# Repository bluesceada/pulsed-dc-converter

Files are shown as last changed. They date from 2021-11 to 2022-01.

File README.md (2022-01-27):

# pulsed-dc-converter
12-20V DC to Pulsed DC Converter

Transforms 12-20V DC to a kind of pulsed DC, compatible with some Power Tools using phase cutting
control (for example Proxxon Micromot), in the range up to around 40W.

Like that, with the respective Adapter, those small Power Tools can be operated from a USB C PD
Power Bank. Adapter Example: https://aliexpress.com/wholesale?SearchText=power+adapter+usb+c+dc+20v

**Progress:**

 [x] Simple loop works on breadboard with similar schematic as in kicad
 
 [x] PCB designed and ordered
 
 [x] PCB tested and working with 12V/1.5A from USB-C Powerbank and 20V/3A from USB-C Power Supply (with respective USB-C Adapters). Populated parts are mainly as in the schematic, except the Zener(D3) in the flyback path is just bridged with a wire, see [21861574f8b53dd02fe86965473d7c7fb414512f](https://github.com/bluesceada/pulsed-dc-converter/commit/21861574f8b53dd02fe86965473d7c7fb414512f)
 
 [x] Use ADC feedback to increase the ON-time of the transistor to maximize power for powerbanks

**Note:** I still have PCBs ([Rev-0.1](https://github.com/bluesceada/pulsed-dc-converter/releases/tag/Rev-0.1)) available, message me if you are interested to get it for net cost, ~1€ + shipping from DE/Germany 🇩🇪. I also still have 2x attiny85 that I could pre-program if needed. The only real PCB-errata is a missing connection of Attiny Pin 5 (PB0) to R1, which is easily bridged.

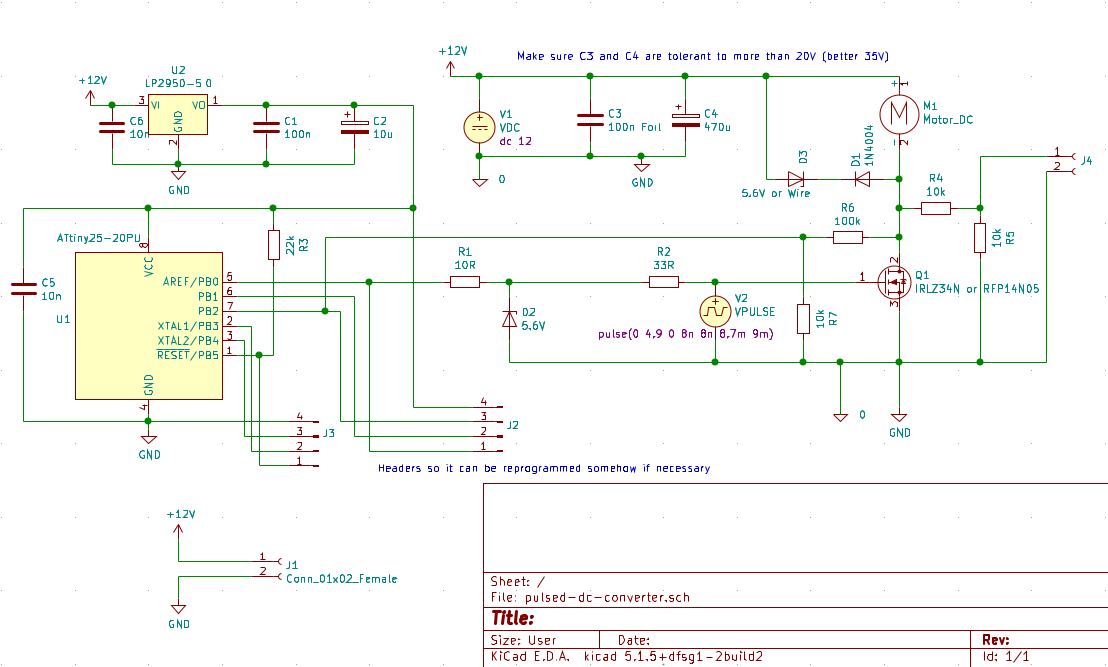
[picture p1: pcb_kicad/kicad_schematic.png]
kicad schematic


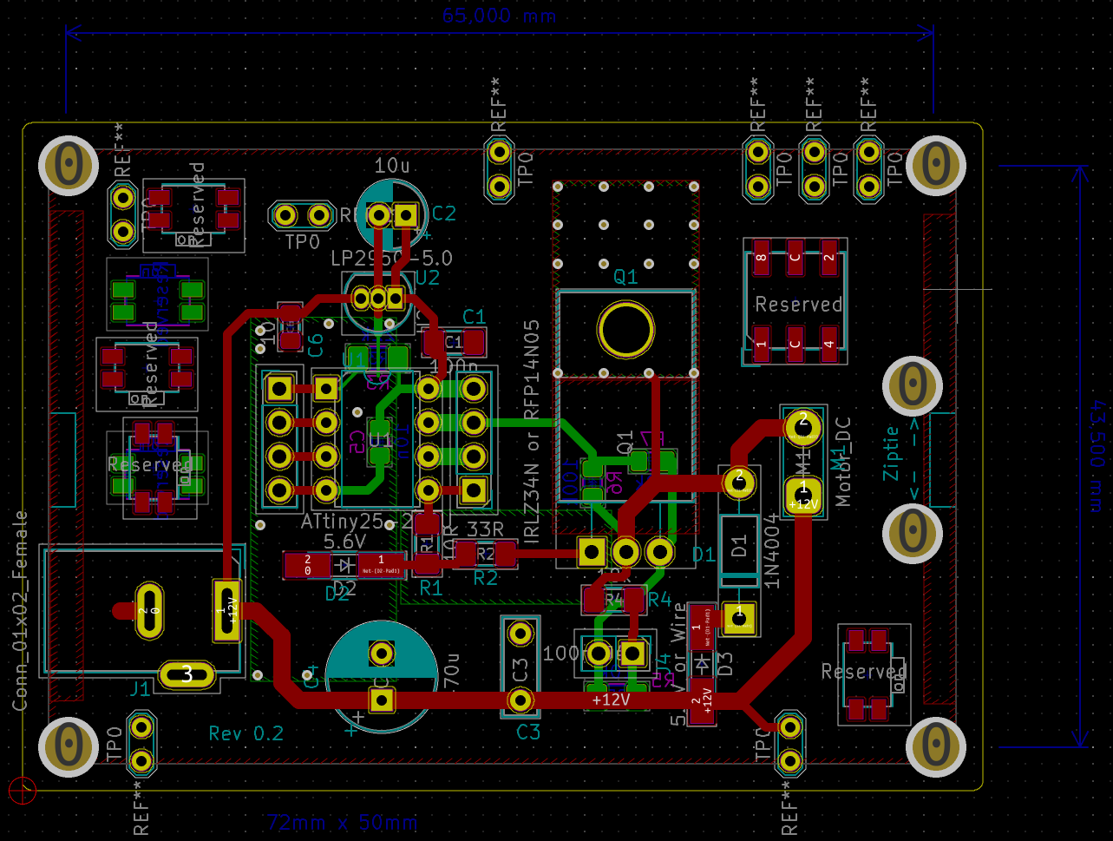
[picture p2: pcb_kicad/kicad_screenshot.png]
kicad pcb


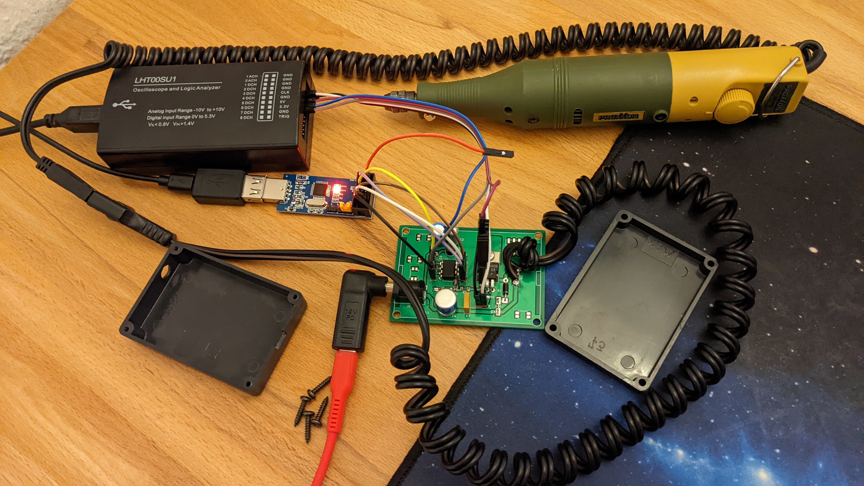
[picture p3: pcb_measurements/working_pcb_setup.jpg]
real hardware pcb setup picture


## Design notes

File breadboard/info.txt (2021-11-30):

You can open the *.pr files with sigrok's "pulseview".

Measurements were on a 19V/12V Supply Voltage from a 65W USB-C Power Supply. Transistors IRLZ34N or RFP14NO5 were used (leading to very similar results). The analog measurements were done on the negative supply voltage of the power tool [1], which is the NMOS transistor's drain.

All measurements done with either a 10x analog probe or a 2x resistor-based voltage divider (because the measurement device range is +/- 10V only). The analog 10x probe is also connected through a long measurement line, and it is a rather cheap device [1]. Thus, do not trust the analog measurements too much. Please consider, they would also be somewhat different on a final PCB.

[1] Proxxon Micromot Typ 28510, 6-18V pulsed DC, 3~40W, 0-20.000 / MIN (RPM).
[2] https://sigrok.org/wiki/Noname_LHT00SU1

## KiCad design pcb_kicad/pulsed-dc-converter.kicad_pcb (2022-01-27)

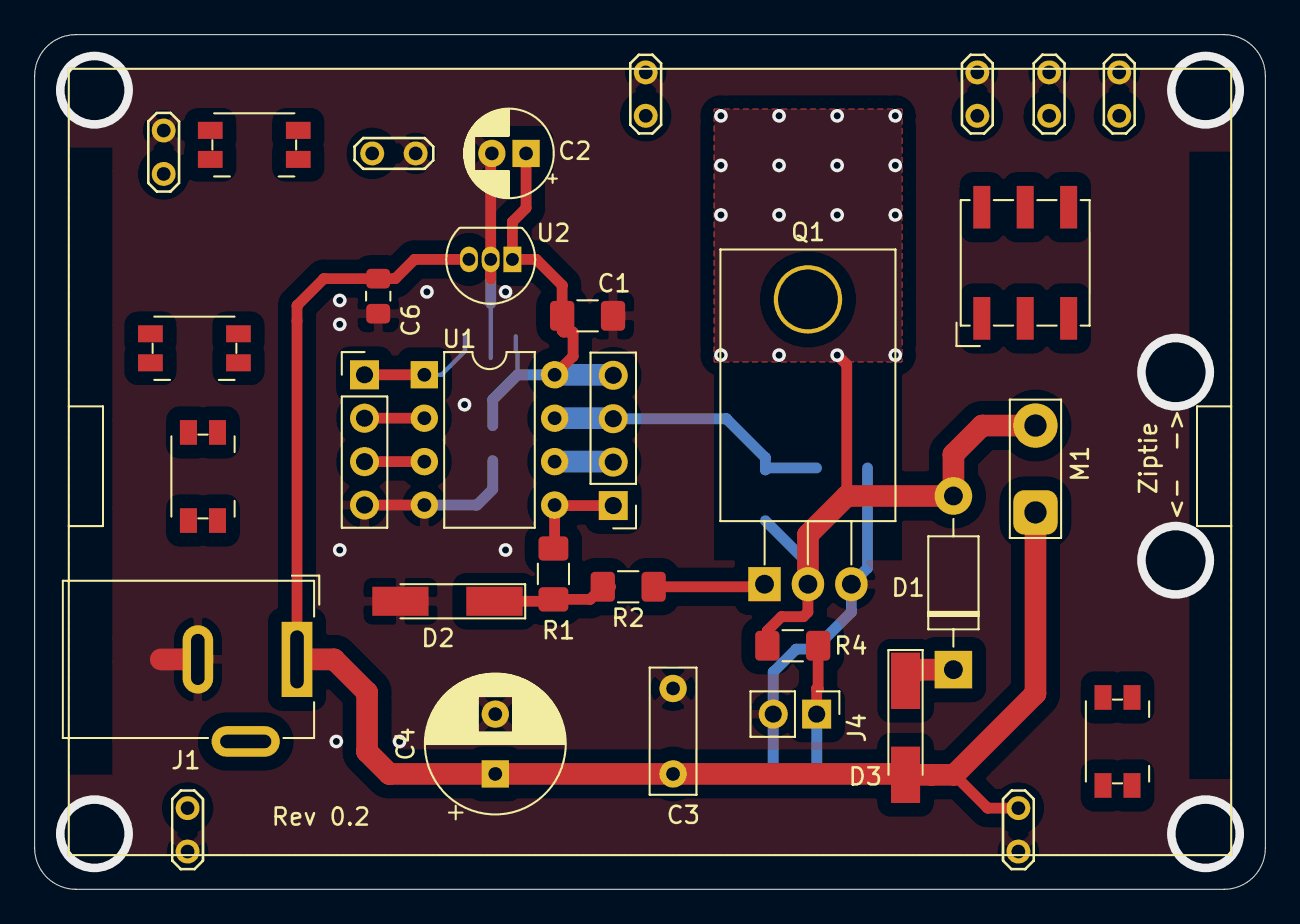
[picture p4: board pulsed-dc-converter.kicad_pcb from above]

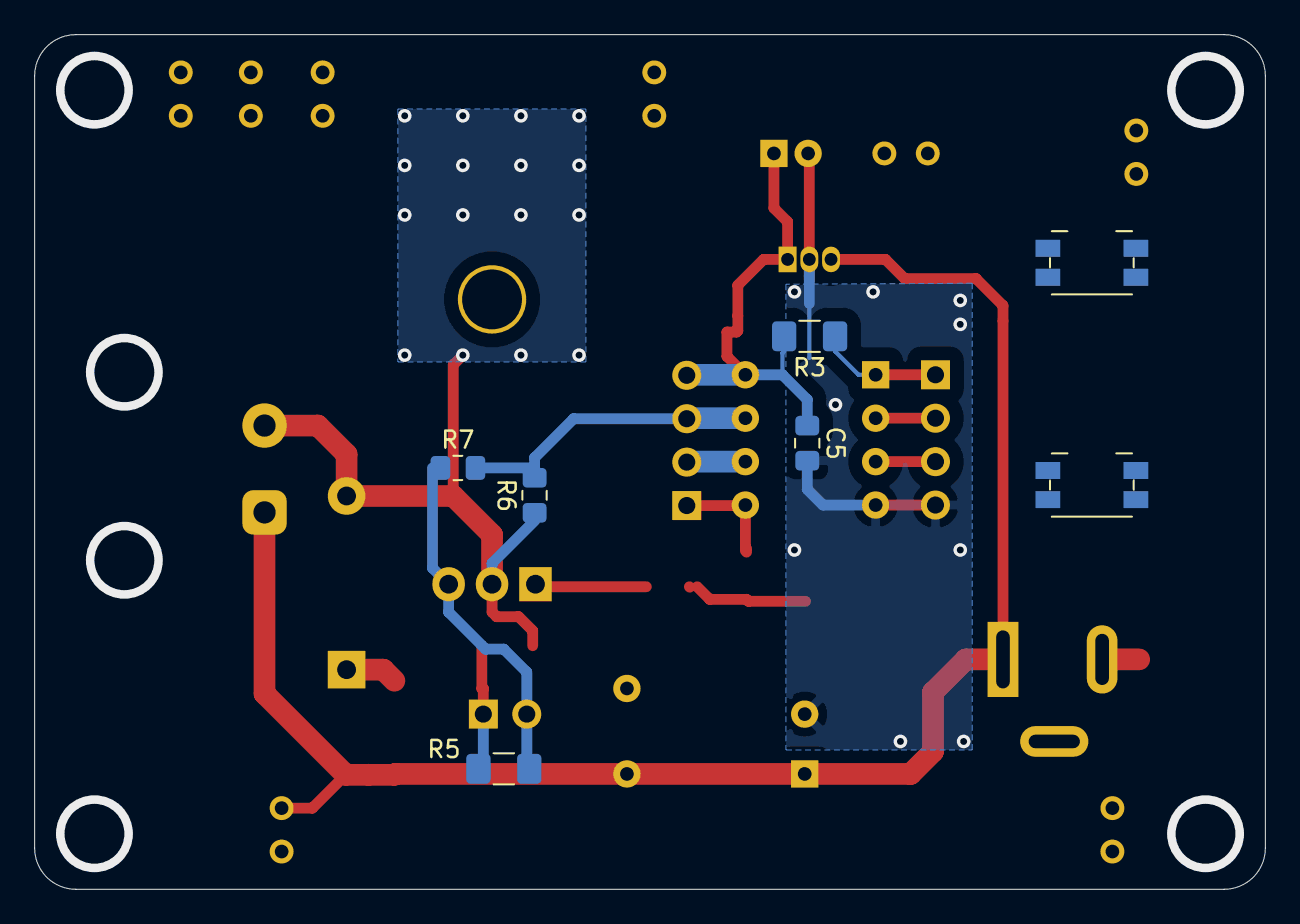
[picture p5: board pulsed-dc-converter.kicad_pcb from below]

Board: 2 copper layers, 72.0 x 50.0 mm, 31 parts (7 on the bottom side), 14 nets.

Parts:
C1: 100n; C_1206_3216Metric_Pad1.42x1.75mm_HandSolder
C2: 10u; CP_Radial_D5.0mm_P2.00mm
C3: 100n Foil; C_Rect_L7.2mm_W2.5mm_P5.00mm_FKS2_FKP2_MKS2_MKP2
C4: 470u; CP_Radial_D8.0mm_P3.50mm
C5, C6: 10n; C_0805_2012Metric_Pad1.15x1.40mm_HandSolder
D1: 1N4004; D_DO-41_SOD81_P10.16mm_Horizontal
D2: 5.6V; D_MiniMELF_Handsoldering
D3: 5.6V or Wire; D_MiniMELF_Handsoldering
J1: Conn_01x02_Female; BarrelJack_Wuerth_6941xx301002
J2: AttinyPins2; PinHeader_1x04_P2.54mm_Vertical
J3: AttinyPins1; PinHeader_1x04_P2.54mm_Vertical
J4: Conn_01x02_Female; PinHeader_1x02_P2.54mm_Vertical
M1: Motor_DC; TestPoint_2Pads_Pitch5.08mm_Drill1.3mm
Q1: IRLZ34N or RFP14N05; TO-220-3_Horizontal_TabDown
R1: 10R; R_1206_3216Metric_Pad1.42x1.75mm_HandSolder
R2: 33R; R_1206_3216Metric_Pad1.42x1.75mm_HandSolder
R3: 22k; R_1206_3216Metric_Pad1.42x1.75mm_HandSolder
R4, R5: 10k; R_1206_3216Metric_Pad1.42x1.75mm_HandSolder
R6: 100k; R_0805_2012Metric_Pad1.15x1.40mm_HandSolder
R7: 10k; R_0805_2012Metric_Pad1.15x1.40mm_HandSolder
Reserved: Panasonic_EVQPUK_EVQPUB
Reserved#2, Reserved#3, Reserved#4, Reserved#5, Reserved#6: Panasonic_EVQPUK_EVQPUB
Reserved#7: Nidec_Copal_SH-7010A
U1: ATtiny25-20PU; DIP-8_W7.62mm
U2: LP2950-5.0; TO-92_Inline

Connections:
0: C1.2, C2.2, C3.2, C4.2, C5.2, C6.2, D2.2, J1.2, J3.4, J4.2, Q1.3, R5.1, R7.1, U1.4, U2.2
+12V: C3.1, C4.1, C6.1, D3.2, J1.1, M1.1, U2.3
unnamed: C1.1, C2.1, C5.1, J2.4, R3.2, U1.8, U2.1
unnamed: D1.1, D3.1
unnamed: D1.2, M1.2, Q1.2, R4.2, R6.1
unnamed: D2.1, R1.1, R2.2
unnamed: J2.1, R1.2, U1.5
unnamed: J2.2, U1.6
unnamed: J2.3, R6.2, R7.2, U1.7
unnamed: J3.1, R3.1, U1.1
unnamed: J3.2, U1.2
unnamed: J3.3, U1.3
unnamed: J4.1, R4.1, R5.2
unnamed: Q1.1, R2.1

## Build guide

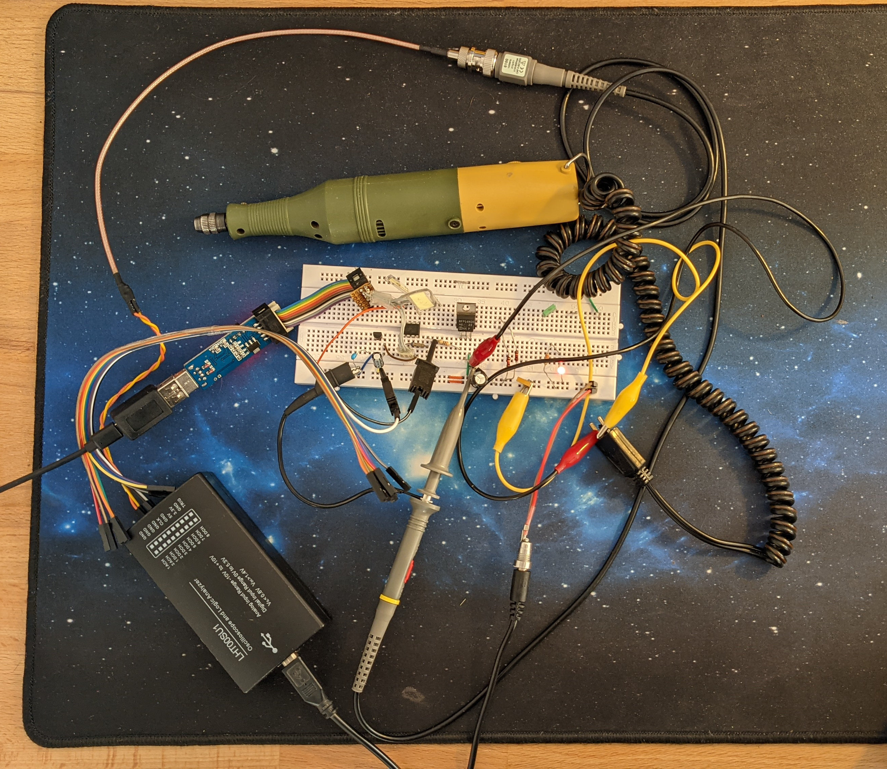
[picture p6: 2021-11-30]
breadboard/breadboard_experimental_setup.jpg

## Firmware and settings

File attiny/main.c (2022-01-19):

/*
 * by Dennis Gnad <dennis@xorn.org>
 * Initial Version: 2021-11-29
 *
 * Yes, I know, the attiny45 is overpowered for this,
 * but it was in my parts drawer ¯\_(ツ)_/¯
 * You can just use the attiny25, software should fit.
 * You might also be able to adjust it for an assembler-only attiny13.
 *
 * For the timer, please use the calibrated internal
 * RC oscillator at 8 MHz (-> 4 MHz with software-set divider)
 * Please also set F_CPU correctly in the Makefile
 *
 */

#include <avr/interrupt.h>
#include <avr/io.h>
#include <avr/sleep.h>
#include <util/delay.h> /* for _delay_ms() */
#include <stdlib.h> /* also contains pseudo random numbers */
#include <stdint.h>

// Previously used simple loop used for measurements on breadboard
void UNUSED_software_only_loop() {
  // 20ms Period 120 Hz / 60 Hz
  const double HIGH_TIME_MS = 8.8;
  const double LOW_TIME_MS = 0.2;
  PORTB &= ~0x1; // reset PB0 to 0 (0V) (Transistor Gate)
  _delay_ms(LOW_TIME_MS);
  PORTB |= 0x1; // set PB0 to 1 (5V) (Transistor Gate)
  _delay_ms(HIGH_TIME_MS);
}

int main(void) {

  // scale all clocks by /2 --> 4 MHz now (with Int. RC)
  CLKPR=(1<<CLKPCE);
  CLKPR=(1<<CLKPS0);

  // PB0 pin as transistor gate output, PB3+PB4 as debug output
  PORTB &= ~(0x1 | 0x8 | 0x10); // pull-downs
  DDRB |= (0x1 | 0x8 | 0x10); // PB0 + PB3 + PB4 output direction (low-Z)
  // PB2 is the input (for ADC)

  // ---- Timer Config ---- //
  // See Table 11-5 in datasheet attiny25/45/85 for various modes
  TCCR0A|=(1<<WGM01)|(1<<WGM00);
  TCCR0B|=(1<<WGM02);
  
  // enable overflow and compare B interrupts
  // (because compare A is the same as overflow in the used mode)
  TIMSK|=(1<<TOIE0)|(1<<OCIE0B);
  
  // 4 MHz / 256 => 64us time steps
  //  -> 1 / 120Hz / 64us = 130
  //     but because my internal RC wasn't calibrated correctly, I needed to use 134
  OCR0B=16; // runs ISR(TIMER0_COMPB_vect) at this time
  OCR0A=134; // resets Timer and runs ISR(TIMER0_OVF_vect) (because of the mode)
  
  //TCCR0B|=(1<<CS00); // no prescaling / use direct clk_I/O
  //TCCR0B|=(1<<CS01)|(1<<CS00); // prescale clk_I/O / 64
  TCCR0B|=(1<<CS02); // prescale clk_I/O / 256
  sei(); //enabling global interrupt
  // ---- END: Timer Config ---- //
  
  // ---- ADC Config ---- //
  // default: use Vcc as ref (5V)
  ADMUX|=(1<<MUX0); // PB2 input
  ADMUX|=(1<<ADLAR); // we will later only use the high 8 bits in ADCH and discard the 2 LSBs
  ADCSRA|=(1<<ADEN);//|(1<<ADATE);
  ADCSRA|=(1<<ADPS1); // ADC prescaler / 4 == 1 MHz
  //ADCSRA|=(1<<ADPS1)|(1<<ADPS0); // ADC prescaler / 8 == 500 kHz
  // ---- END: ADC Config ---- //

  while(1) {
    // interrupt-only operation, loop runs once after each interrupt
    set_sleep_mode(SLEEP_MODE_IDLE);
    sleep_mode();
    //software_only_loop();
  }
  return 0;
}

ISR(TIMER0_COMPB_vect) {
  // fallback to enable transistor again now -- however, it might be
  // already enabled by ADC threshold, but anyway make sure ADC is disabled
  PORTB |= 0x1;
  // disable ADC and its interrupt
  ADCSRA &= ~((1<<ADIE)|(1<<ADEN));
}

ISR(TIMER0_OVF_vect) {
  // enable ADC, start conversion, interrupt enable:
  ADCSRA|=(1<<ADEN)|(1<<ADSC)|(1<<ADIE); 
  
  // disable the transistor every timer overflow
  // we will re-enable after a specific time, or
  // at a specific ADC threshold -- whatever comes first
  // here is a minor delay to align a bit more with ADC conversions
  _delay_ms(0.01);
  PORTB &= ~0x1;
}

// Check the ADC value and compare it. The value is divided by about 10 with a voltage divider
ISR(ADC_vect) {
  static uint8_t Voltage_Up = 0;
  uint8_t Transistor_Drain_V = ADCH;
  
  // checking ADC conversions ....
  PORTB ^= 0x8; // debug
  
  // ADCH values:
  // 255 === 5V <-> measured = 50V
  // 255/50 = 5.1 ~= 1V
  // 26 == ~5V
  // 6 == ~1.2V
  // 10 == ~2V
  
  // the following code works fine with R6=100k, R7=10.5k
  // with 12V from Powerbank and 19.7V from 60W USB-C PD supply
  // at higher rotation speed it minimizes the OFF-time of the transistor
  // (see measurements done with sigrok/pulseview, saved in "pcb_measurements" *.sr files
  //  that you can open with pulseview )
  
  //  check that voltage was up at least once:
  if (Transistor_Drain_V > 26) {
    Voltage_Up = Transistor_Drain_V;
    PORTB |= 0x10; // trigger signal
  }
  // first down-swing
  else if (Transistor_Drain_V < Voltage_Up && Transistor_Drain_V < 25) {
    ADCSRA &= ~((1<<ADIE)|(1<<ADEN)); // disable ADC and its interrupt for a while
    _delay_ms(0.01); // minimum-off-time
    PORTB |= 0x1; // enable transistor again -> get more max. power from power banks
    PORTB |= 0x8; // debug
    Voltage_Up = 0;
    // recommended ADC input resistance: 1..100k, or measurements would be slow
    
  }
}

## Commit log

2021-11-30 sigrok measurements that were done on the breadboard circuit example
2021-11-30 Kicad-designed PCB, including minor Spice Simulation (but seems not very realistic...)
    PCB size 72mm x 50mm with screws in the corners for a specific box size I have here
    Most major change to breadboard measurements:
    - Added Zener in Flyback Path - not sure if this will be really used, but it will be an option on the PCB.
    - Slightly different choices in some capacitors and resistors.
    - No LED
    [pulsed-dc-converter.kicad_pcb, pulsed-dc-converter.sch]
2021-11-30 screenshot of pcb in kicad to get a first impression
2021-12-06 keepout below transistor (metal/drain is there)
    [pulsed-dc-converter.kicad_pcb]
2022-01-19 Final TESTED, working PCB - Tested with following population alternatives and current git attiny code:
    C4: 360u + 100u on TP0 reserve slot (no fitting form factor 470u Capacitor with >20V tolerance was available)
    D3: Wire
    R2: 22 (33 was not available, but should work either way)
    R6: 100k
    R7: 10.5k
    R4: 22.1k
    R5: 10k
    PCB was manufactured at JLCPCB using their recommended settings to create Gerber file with KiCad 5:
    -> https://support.jlcpcb.com/article/149-how-to-generate-gerber-and-drill-files-in-kicad
    [pulsed-dc-converter.kicad_pcb, pulsed-dc-converter.sch]
2022-01-19 Code designated to consume more power from powerbanks using ADC-feedback (not actually measured if it does use more power, but the transistor ON-time is longer)
2022-01-19 Various PCB adjustments for a better Rev 02
    [pulsed-dc-converter.kicad_pcb]
2022-01-19 measurements from PCB (can be opened with sigrok/pulseview)
    for 12V powerbank and 19V from USB-C PD supply, with current git code (ADC-feedback used)
2022-01-19 working pcb setup picture and updated kicad screenshot
2022-01-19 schematic screenshot png
2022-01-27 more rounded PCB corners
    [pulsed-dc-converter.kicad_pcb]
